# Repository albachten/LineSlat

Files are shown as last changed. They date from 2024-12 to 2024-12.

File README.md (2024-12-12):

# LineSlat - Daisy-chained fireworks controllers for line effects

This is an ARM Cortex M0 board with:
* SAMD21 cpu
* USB for programming & serial debug
* Cortex Debug connector for bootloader install & hw debug
* 6 Pairs of PyroClips (6 cues per station)
* 2 RJ45 connectors for daisy-chaining (power & serial comm)
* 915MHz Hope RFM95 Lora module (only populated in the master station)
* OLED display

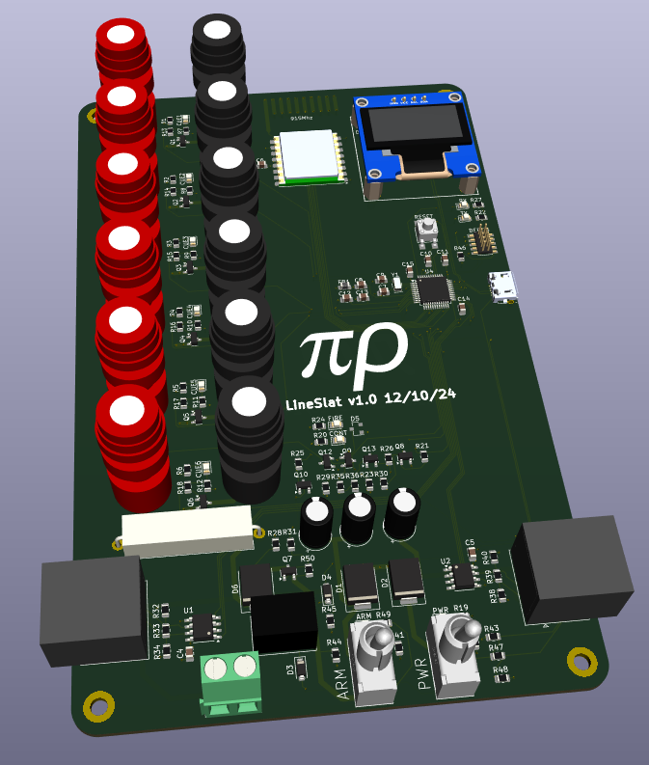
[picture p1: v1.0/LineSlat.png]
PCB


Schematic

[Schematic pdf](v1.0/LineSlat.pdf)

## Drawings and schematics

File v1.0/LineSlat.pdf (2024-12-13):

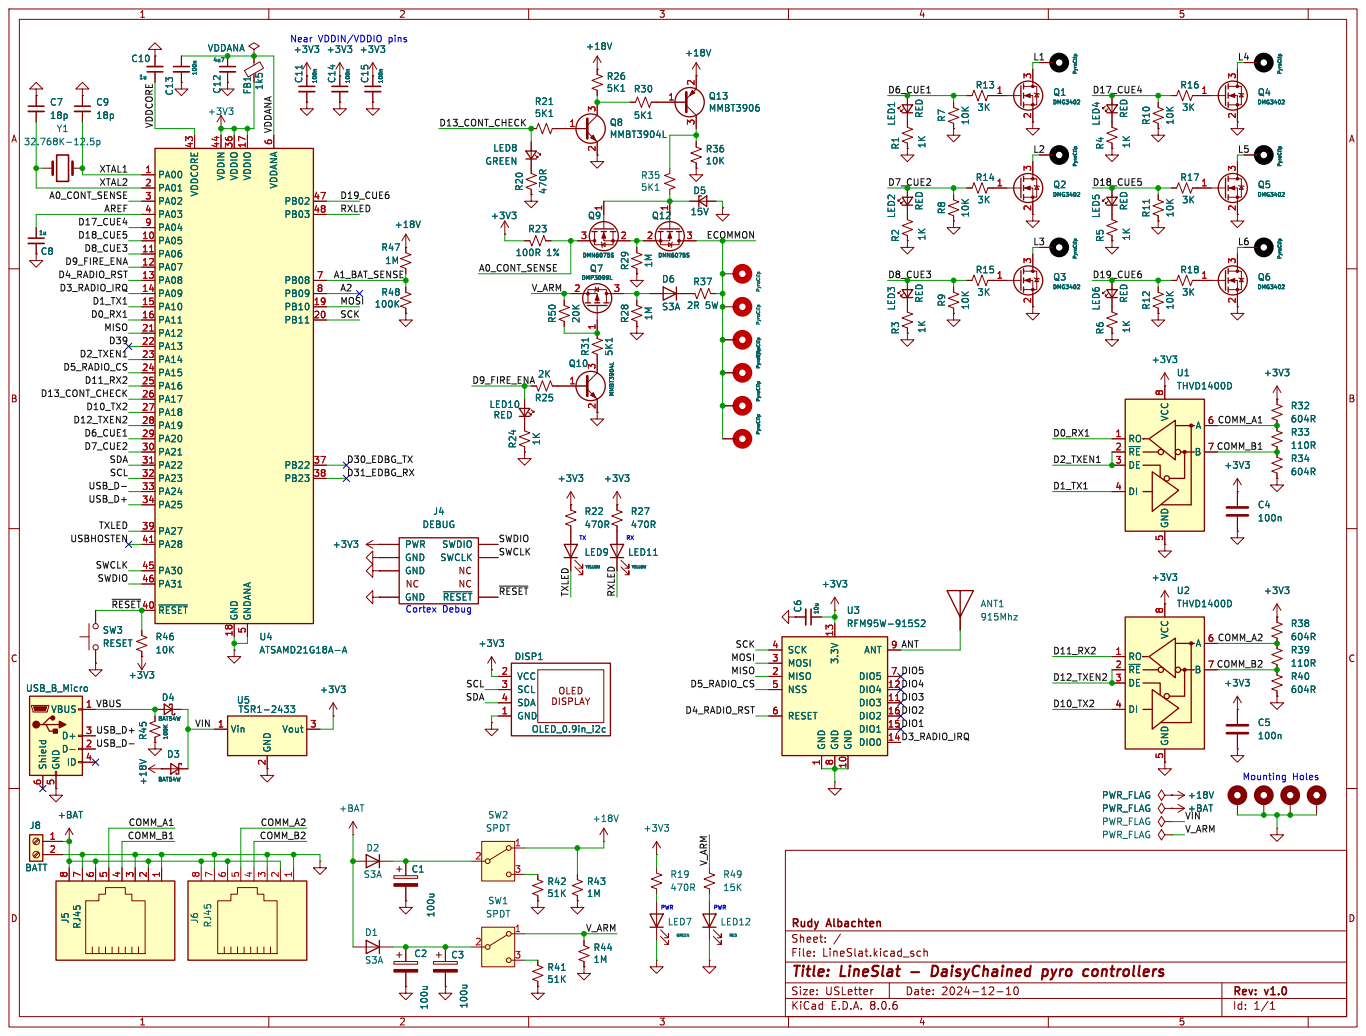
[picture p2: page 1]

Near VDDIN/VDDIO pins

~{RESET} SWDIO
DISPLAY GND 1 VCC 2 SCL 3 SDA 4 DISP1OLED_0.9in_i2cR44

1 GND 10 DIO3 11 DIO4 12 3.3V 13 DIO0 14 DIO1 15 DIO2 16 MISO 2 MOSI 3 SCK 4 NSS 5 RESET 6 DIO5 7 GND

1 DISP1OLED_0.9in_i2c GND 1 VCC 2 SCL 3 SDA 4 R44

File: LineSlat.kicad_sch Sheet: / Rudy Albachten

Id: 1/1 Title: LineSlat - DaisyChained pyro controllers

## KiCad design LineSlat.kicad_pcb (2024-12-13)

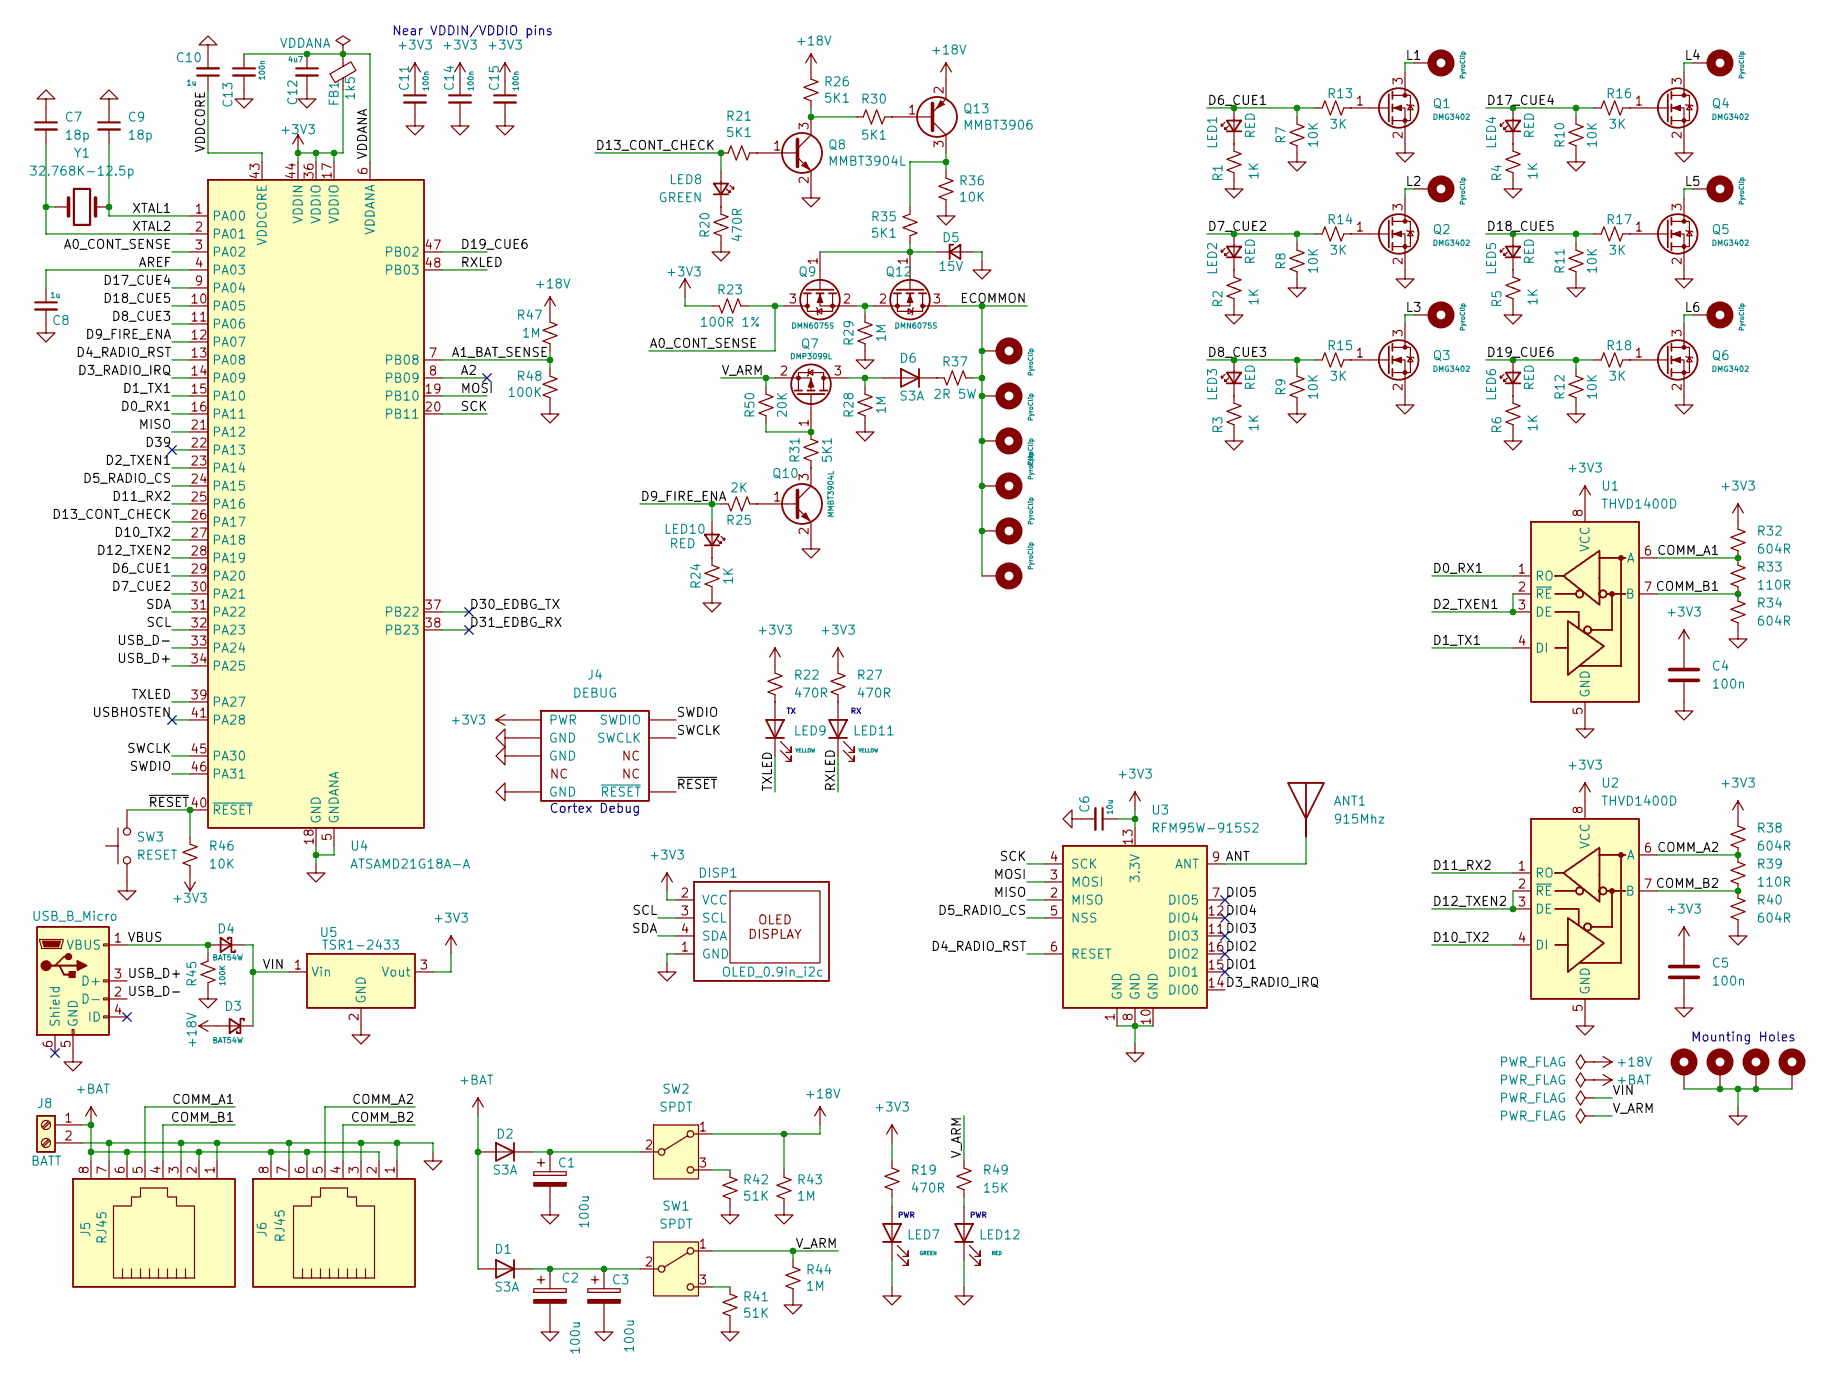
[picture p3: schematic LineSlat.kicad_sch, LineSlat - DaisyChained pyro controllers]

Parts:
ANT1: 915Mhz; Texas_SWRA416_868MHz_915MHz; Mouser Part Number N/A
C1, C2, C3: 100u; CP_Radial_D6.3mm_P2.50mm; Mouser Part Number 710-860010573007
C4, C5, C11, C13, C14, C15: 100n; C_0805_2012Metric; Mouser Part Number 80-C0805C104M5RACTM
C6: 10u; C_0805_2012Metric; Mouser Part Number LMK212AC6106KD-T
C7, C9: 18p; C_0805_2012Metric; Mouser Part Number 80-C0805C180J5GAC
C8, C10: 1u; C_0805_2012Metric; Mouser Part Number 710-885012207022
C12: 4u7; C_0805_2012Metric; Mouser Part Number 187-CL21A475KPFNNNF
CLIP1, CLIP2, CLIP3, CLIP4, CLIP5, CLIP6: PyroClip; PyroClipBlack; Mouser Part Number N/A
CLIP7, CLIP8, CLIP9, CLIP10, CLIP11, CLIP12: PyroClip; PyroClipRed; Mouser Part Number N/A
D1, D2, D6: S3A; D_SMC; Mouser Part Number 512-S3A
D3, D4: BAT54W; D_SOD-123; Mouser Part Number 78-BAT54W-HG3-18
D5: 15V; D_SOT-23_ANK; Mouser Part Number 863-BZX84C15LT1G
DISP1: OLED_0.9in_i2c; OLED_0.9in_i2c_weewooday; Mouser Part Number N/A
FB1: 1k5; L_0805_2012Metric; Mouser Part Number 810-MMZ2012Y152BT000
H1, H2, H3, H4: MountingHole; MountingHole_3.2mm_M3_ISO7380_Pad; Mouser Part Number N/A
J4: DEBUG; CortexDebugSMD; Mouser Part Number 640-BD12510A305580LB
J5, J6: RJ45; RJ45_SS-700810-NF; Mouser Part Number 530-SS-700810-NF
J7: USB_B_Micro; USB_Micro-B_Amphenol_10118194_Horizontal; Mouser Part Number 649-10118194-0011LF
J8: BATT; TerminalBlock_1x02_P5.08mm; Mouser Part Number 649-VI02215200J0G
LED1, LED2, LED3, LED4, LED5, LED6, LED10, LED12: RED; LED_0805_2012Metric; Mouser Part Number 710-150080RS75000
LED7, LED8: GREEN; LED_0805_2012Metric; Mouser Part Number 710-150080RS75000
LED9, LED11: YELLOW; LED_0805_2012Metric; Mouser Part Number 710-150080YS75000
Q1, Q2, Q3, Q4, Q5, Q6: DMG3402; SOT-23; Mouser Part Number 621-DMG3402L-7
Q7: DMP3099L; SOT-23; Mouser Part Number 621-DMP3099L-13
Q8, Q10: MMBT3904L; SOT-23; Mouser Part Number 771-MMBT3904VL
Q9, Q12: DMN6075S; SOT-23; Mouser Part Number 621-DMN6075S-7
Q13: MMBT3906; SOT-23; Mouser Part Number 863-MMBT3906LT1G
R1, R2, R3, R4, R5, R6, R24: 1K; R_0805_2012Metric; Mouser Part Number 71-CRCW08051K00FKEC
R7, R8, R9, R10, R11, R12, R36, R46: 10K; R_0805_2012Metric; Mouser Part Number 71-CRCW0805-10K-E3
R13, R14, R15, R16, R17, R18: 3K; R_0805_2012Metric; Mouser Part Number 652-CR0805JW-302ELF
R19, R20, R22, R27: 470R; R_0805_2012Metric; Mouser Part Number 71-CRCW0805-470-E3
R21, R26, R30, R31, R35: 5K1; R_0805_2012Metric; Mouser Part Number 71-CRCW08055K10JNEB
R23: 100R 1%; R_0805_2012Metric; Mouser Part Number 603-RT0805FRE07100RL
R25: 2K; R_0805_2012Metric; Mouser Part Number 652-CR0805JW-202ELF
R28, R29, R43, R44, R47: 1M; R_0805_2012Metric; Mouser Part Number 652-CHV0805FX1004ELF
R32, R34, R38, R40: 604R; R_0805_2012Metric; Mouser Part Number 603-RC0805FR-07604RL
R33, R39: 110R; R_0805_2012Metric; Mouser Part Number 652-CR0805JW-111ELF
R37: 2R 5W; R_Axial_Power_L25.0mm_W6.4mm_P27.94mm; Mouser Part Number 588-TUW5J2R0E
R41, R42: 51K; R_0805_2012Metric; Mouser Part Number 71-CRCW08055K10JNEB
R45, R48: 100K; R_0805_2012Metric; Mouser Part Number 652-CR0805JW-104ELF
R49: 15K; R_0805_2012Metric; Mouser Part Number 71-CRCW0805-15K-E3
R50: 20K; R_0805_2012Metric; Mouser Part Number 652-CR0805JW-203ELF
SW1, SW2: SPDT; spdt_100SP1T1B2M2QE; Mouser Part Number 612-100SP1T1B2M2QE
SW3: RESET; TL3305B_SPST_PushButton; Mouser Part Number 652-CR0805JW-104ELF
U1, U2: THVD1400D; SOIC-8_3.9x4.9mm_P1.27mm; Mouser Part Number 595-THVD1400DR
U3: RFM95W-915S2; RFM95CW; Mouser Part Number 223-RFM95W-915S2
U4: ATSAMD21G18A-A; TQFP-48_7x7mm_P0.5mm; Mouser Part Number 556-ATSAMD21G18A-MU
U5: TSR1-2433; Converter_DCDC_TRACO_TSR1-xxxxE_THT; Mouser Part Number 495-TSR-1-2433
Y1: 32.768K-12.5p; Crystal_SMD_G8-2Pin_3.2x1.5mm; Mouser Part Number 520-327-12.5-34B

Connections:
+3V3: C4.1, C5.1, C6.1, C11.1, C14.1, C15.1, DISP1.2 (VCC), FB1.1, J4.1 (PWR), R19.1, R22.1, R23.2, R27.1, R32.1, R38.1, R46.2, U1.8 (VCC), U2.8 (VCC), U3.13 (3.3V), U4.17 (VDDIO), U4.36 (VDDIO), U4.44 (VDDIN), U5.3 (Vout)
+18V: D3.2 (A), Q13.2 (E), R26.2, R43.2, R47.1, SW2.1 (A)
+BAT: D1.2 (A), D2.2 (A), J5.2, J5.6, J5.8, J6.2, J6.6, J6.8, J8.1
/A0_CONT_SENSE: Q9.3 (D), R23.1, U4.3 (PA02)
/A1_BAT_SENSE: R47.2, R48.1, U4.7 (PB08)
/A2: U4.8 (PB09)
/ANT: ANT1.1 (A), U3.9 (ANT)
/AREF: C8.1, U4.4 (PA03)
/COMM_A1: J5.5, R32.2, R33.1, U1.6 (A)
/COMM_A2: J6.5, R38.2, R39.1, U2.6 (A)
/COMM_B1: J5.4, R33.2, R34.1, U1.7 (B)
/COMM_B2: J6.4, R39.2, R40.1, U2.7 (B)
/D0_RX1: U1.1 (RO), U4.16 (PA11)
/D1_TX1: U1.4 (DI), U4.15 (PA10)
/D2_TXEN1: U1.2 (~RE), U1.3 (DE), U4.23 (PA14)
/D3_RADIO_IRQ: U3.14 (DIO0), U4.14 (PA09)
/D4_RADIO_RST: U3.6 (RESET), U4.13 (PA08)
/D5_RADIO_CS: U3.5 (NSS), U4.24 (PA15)
/D6_CUE1: LED1.2 (A), R7.2, R13.1, U4.29 (PA20)
/D7_CUE2: LED2.2 (A), R8.2, R14.1, U4.30 (PA21)
/D8_CUE3: LED3.2 (A), R9.2, R15.1, U4.11 (PA06)
/D9_FIRE_ENA: LED10.2 (A), R25.1, U4.12 (PA07)
/D10_TX2: U2.4 (DI), U4.27 (PA18)
/D11_RX2: U2.1 (RO), U4.25 (PA16)
/D12_TXEN2: U2.2 (~RE), U2.3 (DE), U4.28 (PA19)
/D13_CONT_CHECK: LED8.2 (A), R21.2, U4.26 (PA17)
/D17_CUE4: LED4.2 (A), R10.2, R16.1, U4.9 (PA04)
/D18_CUE5: LED5.2 (A), R11.2, R17.1, U4.10 (PA05)
/D19_CUE6: LED6.2 (A), R12.2, R18.1, U4.47 (PB02)
/D30_EDBG_TX: U4.37 (PB22)
/D31_EDBG_RX: U4.38 (PB23)
/D39: U4.22 (PA13)
/DIO1: U3.15 (DIO1)
/DIO2: U3.16 (DIO2)
/DIO3: U3.11 (DIO3)
/DIO4: U3.12 (DIO4)
/DIO5: U3.7 (DIO5)
/ECOMMON: CLIP7.1, CLIP8.1, CLIP9.1, CLIP10.1, CLIP11.1, CLIP12.1, Q12.3 (D), R37.1
/L1: CLIP1.1, Q1.3 (D)
/L2: CLIP2.1, Q2.3 (D)
/L3: CLIP3.1, Q3.3 (D)
/L4: CLIP4.1, Q4.3 (D)
/L5: CLIP5.1, Q5.3 (D)
/L6: CLIP6.1, Q6.3 (D)
/MISO: U3.2 (MISO), U4.21 (PA12)
/MOSI: U3.3 (MOSI), U4.19 (PB10)
/RXLED: LED11.1 (K), U4.48 (PB03)
/SCK: U3.4 (SCK), U4.20 (PB11)
/SCL: DISP1.3 (SCL), U4.32 (PA23)
/SDA: DISP1.4 (SDA), U4.31 (PA22)
/SWCLK: J4.4 (SWCLK), U4.45 (PA30)
/SWDIO: J4.2 (SWDIO), U4.46 (PA31)
/TXLED: LED9.1 (K), U4.39 (PA27)
/USBHOSTEN: U4.41 (PA28)
/USB_D+: J7.3 (D+), U4.34 (PA25)
/USB_D-: J7.2 (D-), U4.33 (PA24)
/VBUS: D4.2 (A), J7.1 (VBUS), R45.2
/VDDANA: C12.1, C13.1, FB1.2, U4.6 (VDDANA)
/VDDCORE: C10.1, U4.43 (VDDCORE)
/VIN: D3.1 (K), D4.1 (K), U5.1 (Vin)
/V_ARM: Q7.2 (S), R44.2, R49.1, R50.2, SW1.1 (A)
/XTAL1: C9.2, U4.1 (PA00), Y1.2
/XTAL2: C7.2, U4.2 (PA01), Y1.1
/~RESET: J4.10 (~RESET), R46.1, SW3.2, U4.40 (~RESET)
GND: C1.2, C2.2, C3.2, C4.2, C5.2, C6.2, C7.1, C8.2, C9.1, C10.2, C11.2, C12.2, C13.2, C14.2, C15.2, D5.2 (A), DISP1.1 (GND), H1.1, H2.1, H3.1, H4.1, J4.3 (GND), J4.5 (GND), J4.9 (GND), J5.1, J5.3, J5.7, J6.1, J6.3, J6.7, J7.5 (GND), J8.2, LED7.1 (K), LED12.1 (K), Q1.2 (S), Q2.2 (S), Q3.2 (S), Q4.2 (S), Q5.2 (S), Q6.2 (S), Q8.2 (E), Q10.2 (E), R1.1, R2.1, R3.1, R4.1, R5.1, R6.1, R7.1, R8.1, R9.1, R10.1, R11.1, R12.1, R20.1, R24.1, R28.1, R29.1, R34.2, R36.1, R40.2, R41.1, R42.1, R43.1, R44.1, R45.1, R48.2, SW3.1, U1.5 (GND), U2.5 (GND), U3.1 (GND), U3.8 (GND), U3.10 (GND), U4.5 (GNDANA), U4.18 (GND), U4.35 (GND), U4.42 (GND), U5.2 (GND)
unnamed: C2.1, C3.1, D1.1 (K), SW1.2 (B)
unnamed: C1.1, D2.1 (K), SW2.2 (B)
unnamed: D5.1 (K), Q9.1 (G), Q12.1 (G), R35.1
unnamed: D6.2 (A), Q7.3 (D), R28.2
unnamed: D6.1 (K), R37.2
unnamed: LED1.1 (K), R1.2
unnamed: LED2.1 (K), R2.2
unnamed: LED3.1 (K), R3.2
unnamed: LED4.1 (K), R4.2
unnamed: LED5.1 (K), R5.2
unnamed: LED6.1 (K), R6.2
unnamed: LED7.2 (A), R19.2
unnamed: LED8.1 (K), R20.2
unnamed: LED9.2 (A), R22.2
unnamed: LED10.1 (K), R24.2
unnamed: LED11.2 (A), R27.2
unnamed: LED12.2 (A), R49.2
unnamed: Q1.1 (G), R13.2
unnamed: Q2.1 (G), R14.2
unnamed: Q3.1 (G), R15.2
unnamed: Q4.1 (G), R16.2
unnamed: Q5.1 (G), R17.2
unnamed: Q6.1 (G), R18.2
unnamed: Q7.1 (G), R31.2, R50.1
unnamed: Q8.1 (B), R21.1
unnamed: Q8.3 (C), R26.1, R30.2
unnamed: Q10.1 (B), R25.2
unnamed: Q10.3 (C), R31.1
unnamed: Q9.2 (S), Q12.2 (S), R29.2
unnamed: Q13.1 (B), R30.1
unnamed: Q13.3 (C), R35.2, R36.2
unnamed: R41.2, SW1.3 (C)
unnamed: R42.2, SW2.3 (C)

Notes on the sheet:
PWR
Near VDDIN/VDDIO pins
Mounting Holes
Cortex Debug

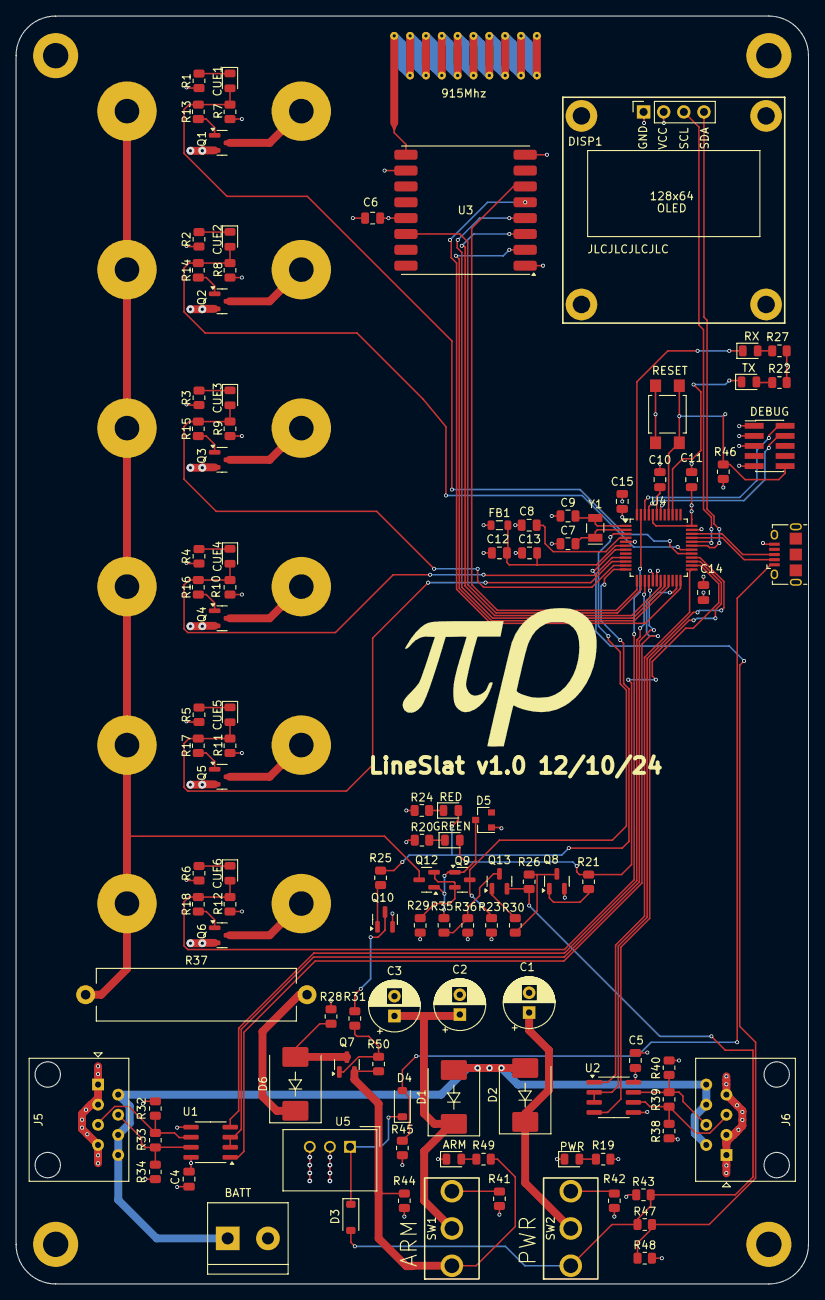
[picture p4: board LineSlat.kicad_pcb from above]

Board: 4 copper layers, 100.0 x 160.0 mm, 130 parts (1 on the bottom side), 88 nets.

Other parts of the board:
LOGO1, LOGO2: LOGO; pirho

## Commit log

2024-12-13 Change diodes and regulator
    Changed regulator from TSR-1-2433E to TSR-1-2433
    This changes Vin minimum from 6V to 4.76V
    Changed schottky diodes to BAT54W.
    This fixes 2 issues:
    - reverse voltage 20V -> 30V (not enough margin for ~20V LiPo)
    - forward voltage drop 600mV -> 250mV (5V-600mV is below Vin min of 3.3V regulator)
    [LineSlat.kicad_pcb, LineSlat.kicad_sch]
2026-10-14 Added files for 3d printed boxes using openscad
2026-10-22 Add brown-out, chain limits and short detection to spec; add SUGGESTIONS
    - SOFTWARE_SPEC: end the fire pulse when the match burns open, document
    C1 hold-up during chain fires, define the supported v2.0 chain (master
    in the middle, 4 + 3 slaves, at most 10 ft per link), and add a LOW
    continuity result shown only on the local OLED.
    - SUGGESTIONS: schematic review, with corrected Cat5 resistance, chain
    sag and hold-up analysis, RJ45 contacts checked, staggered firing
    considered and dropped.
2026-10-22 Drop the match-open pulse cutoff from the spec
    Once a match burns open its current is already near zero, so ending the
    pulse then does not shorten the cable sag or reduce R37 heating. The
    shorted-cue cutoff stays.
2026-10-22 Allow the radio ack during a fire in rule 11
    Only the chain's master has a radio, and it runs from its own battery,
    so its 3V3 doesn't depend on the cable. RS-485 stays quiet during a
    fire (pyro radio protocol §5.6).
